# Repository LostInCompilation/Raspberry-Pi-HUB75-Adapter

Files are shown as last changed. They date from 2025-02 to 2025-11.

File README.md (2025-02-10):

# Raspberry Pi Zero HUB75 LED-Matrix Controller / Adapter

## Features
- Everything on board
- 2 parralel chains of LED-Matrix panels (each chain can habe many panels)
- Suppport for HUB75 and HUB75E (ABCD**E** address lines)
- Power for LED-Matrix panels comes from board
- I2C extension port for custom hardware (light sensor, accelrometer, ...)
- Reverse polarity protection

## 3D Board view
<p align="center" width="100%">
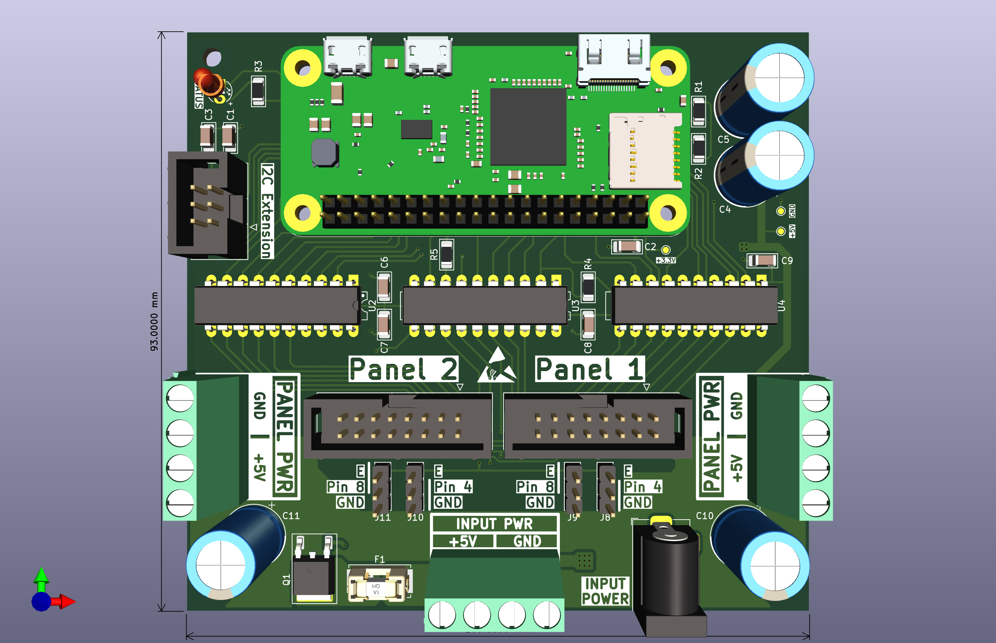
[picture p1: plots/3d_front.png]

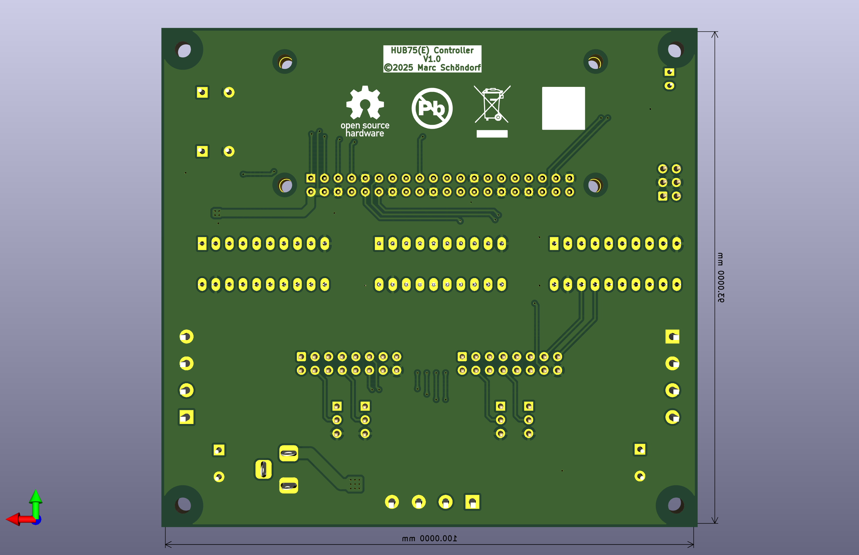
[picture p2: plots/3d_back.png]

</p>

## Board
<p align="center" width="100%">
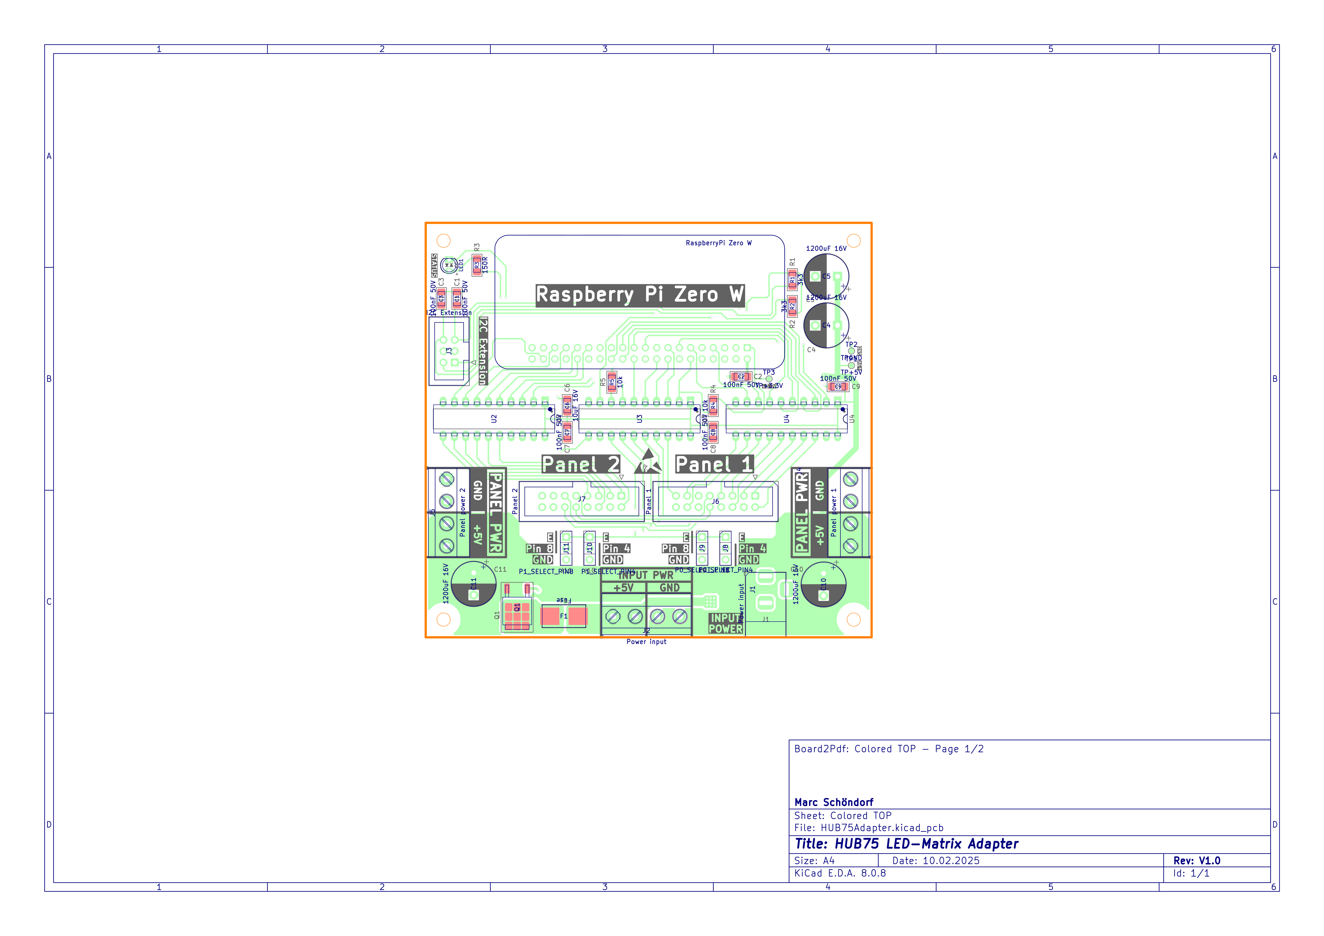
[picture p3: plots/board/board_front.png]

</p>

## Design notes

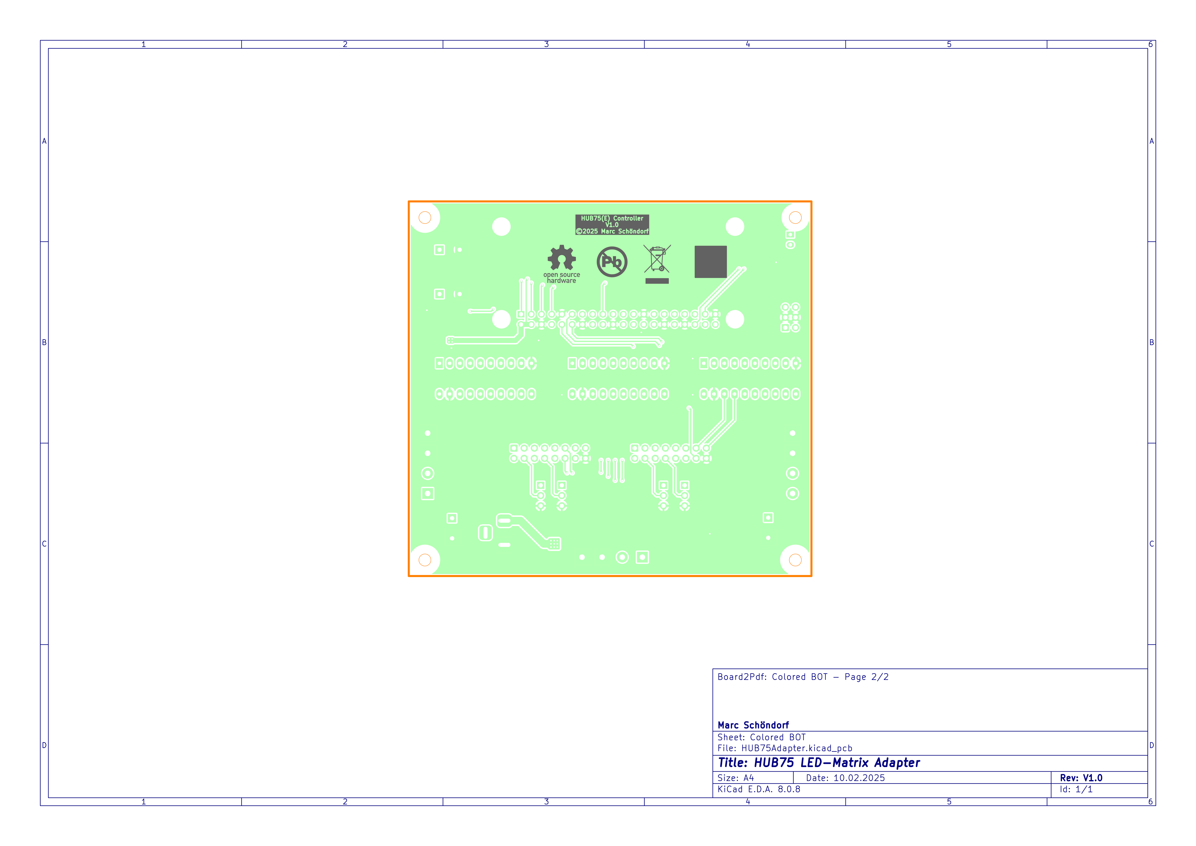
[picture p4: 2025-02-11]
plots/board/board_back.png

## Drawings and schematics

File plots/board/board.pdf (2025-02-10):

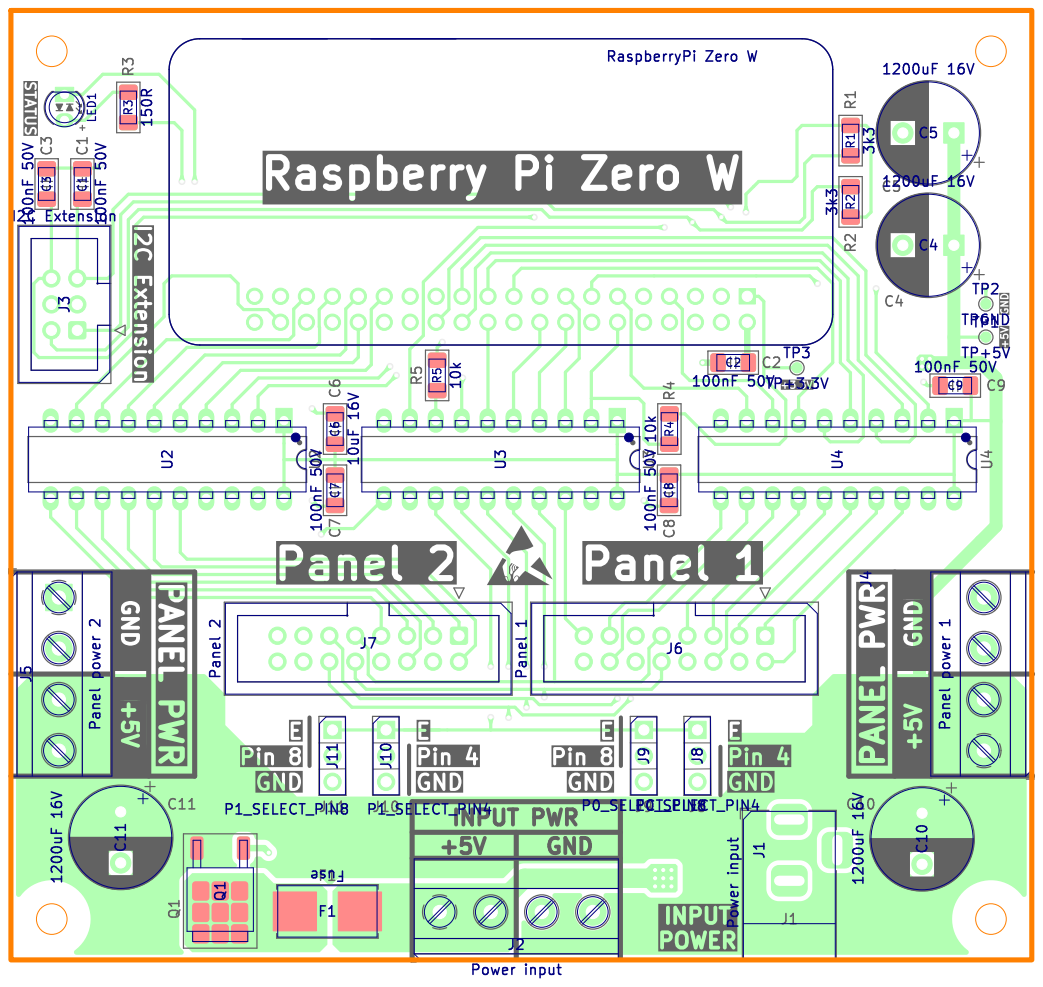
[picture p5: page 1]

INPUT | | PWR

GND

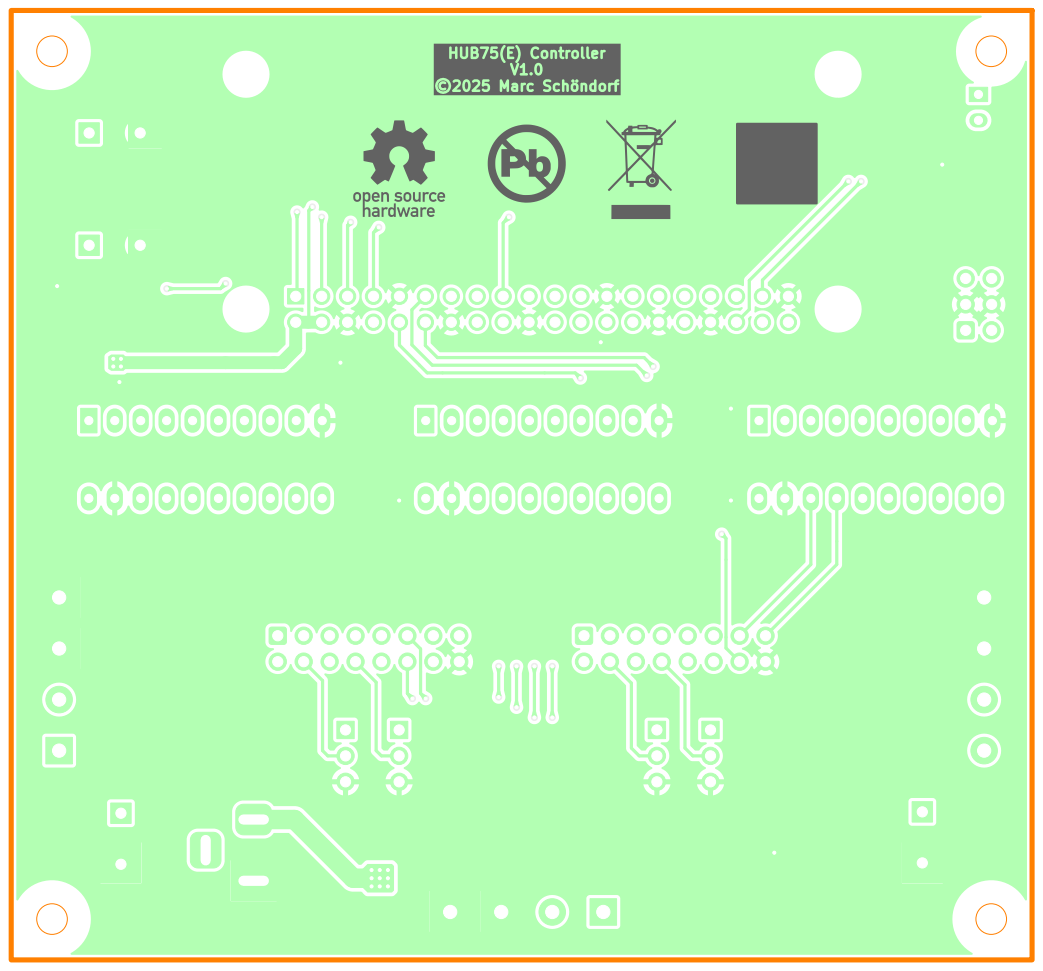
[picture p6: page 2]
D Date: 10.02.2025 KiCad; E.D.A. 8.0.8 Size: A4; Rev: V1.0; Id: 1/1 Title: HUB75 LED-Matrix; Adapter File: HUB75Adapter.kicad_pcb Sheet: Colored; BOT Marc þÿSchöndorf Board2Pdf:; Colored; BOT -; Page 2/2

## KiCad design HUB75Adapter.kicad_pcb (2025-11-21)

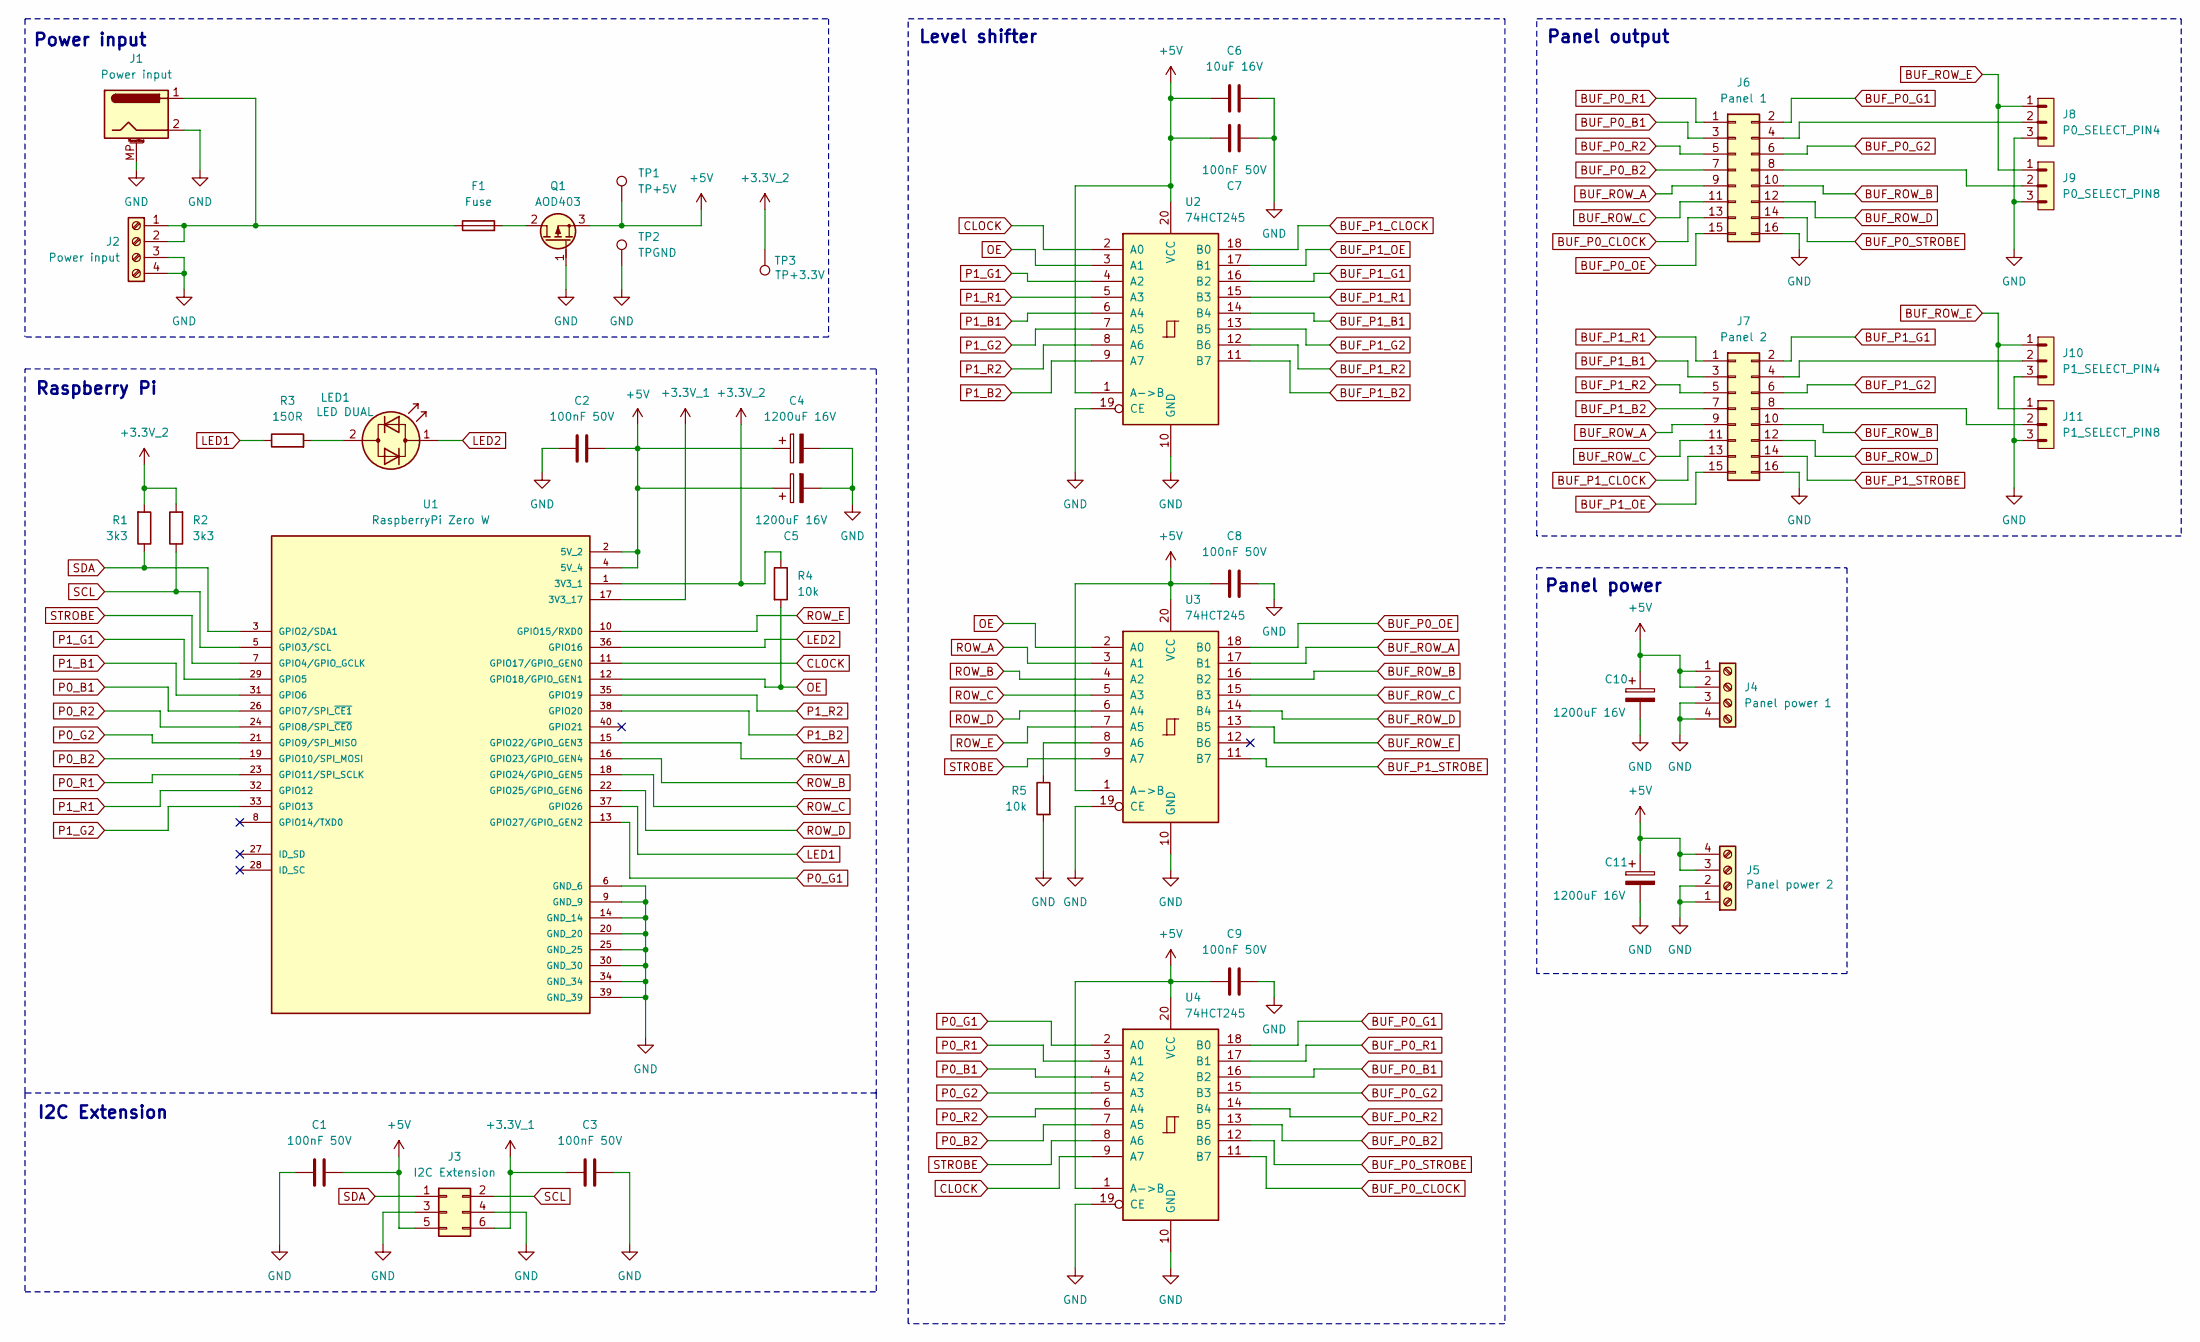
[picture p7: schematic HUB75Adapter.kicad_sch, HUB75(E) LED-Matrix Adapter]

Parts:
C1, C2, C3, C7, C8, C9: 100nF 50V; C_1206_3216Metric_Pad1.42x1.75mm_HandSolder
C4, C5, C10, C11: 1200uF 16V; CP_Radial_D10.0mm_P5.00mm
C6: 10uF 16V; C_1206_3216Metric_Pad1.42x1.75mm_HandSolder
F1: Fuse; Fuseholder_Littelfuse_Nano2_154x
J1: Power input; BarrelJack_Horizontal
J2: Power input; TerminalBlock_Phoenix_MKDS-1,5-4_1x04_P5.00mm_Horizontal
J3: I2C Extension; IDC-Header_2x03_P2.54mm_Vertical
J4: Panel power 1; TerminalBlock_Phoenix_MKDS-1,5-4_1x04_P5.00mm_Horizontal
J5: Panel power 2; TerminalBlock_Phoenix_MKDS-1,5-4_1x04_P5.00mm_Horizontal
J6: Panel 1; IDC-Header_2x08_P2.54mm_Vertical
J7: Panel 2; IDC-Header_2x08_P2.54mm_Vertical
J8: P0_SELECT_PIN4; PinHeader_1x03_P2.54mm_Vertical
J9: P0_SELECT_PIN8; PinHeader_1x03_P2.54mm_Vertical
J10: P1_SELECT_PIN4; PinHeader_1x03_P2.54mm_Vertical
J11: P1_SELECT_PIN8; PinHeader_1x03_P2.54mm_Vertical
LED1: LED DUAL; LED_D3.0mm_BiDir
Q1: AOD403; TO-252-2
R1, R2: 3k3; R_1206_3216Metric_Pad1.42x1.75mm_HandSolder
R3: 150R; R_1206_3216Metric_Pad1.42x1.75mm_HandSolder
R4, R5: 10k; R_1206_3216Metric_Pad1.42x1.75mm_HandSolder
TP1: TP+5V; TestPoint_Pad_D1.0mm
TP2: TPGND; TestPoint_Pad_D1.0mm
TP3: TP+3.3V; TestPoint_Pad_D1.0mm
U1: RaspberryPi Zero W; RaspberryPi Zero; PARTREV April 2024
U2, U3, U4: 74HCT245; DIP-20_W7.62mm_LongPads

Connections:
+3.3V_1: C3.2, J3.6, U1.17 (3V3_17)
+3.3V_2: R1.2, R2.2, R4.1, TP3.1, U1.1 (3V3_1)
+5V: C1.1, C2.2, C4.1, C5.1, C6.1, C7.1, C8.1, C9.1, C10.1, C11.1, J3.5, J4.1, J4.2, J5.3, J5.4, Q1.3 (S), TP1.1, U1.2 (5V_2), U1.4 (5V_4), U2.1 (A->B), U2.20 (VCC), U3.1 (A->B), U3.20 (VCC), U4.1 (A->B), U4.20 (VCC)
BUF_P0_B1: J6.3, U4.16 (B2)
BUF_P0_B2: J6.7, U4.13 (B5)
BUF_P0_CLOCK: J6.13, U4.11 (B7)
BUF_P0_G1: J6.2, U4.18 (B0)
BUF_P0_G2: J6.6, U4.15 (B3)
BUF_P0_OE: J6.15, U3.18 (B0)
BUF_P0_R1: J6.1, U4.17 (B1)
BUF_P0_R2: J6.5, U4.14 (B4)
BUF_P0_STROBE: J6.14, U4.12 (B6)
BUF_P1_B1: J7.3, U2.14 (B4)
BUF_P1_B2: J7.7, U2.11 (B7)
BUF_P1_CLOCK: J7.13, U2.18 (B0)
BUF_P1_G1: J7.2, U2.16 (B2)
BUF_P1_G2: J7.6, U2.13 (B5)
BUF_P1_OE: J7.15, U2.17 (B1)
BUF_P1_R1: J7.1, U2.15 (B3)
BUF_P1_R2: J7.5, U2.12 (B6)
BUF_P1_STROBE: J7.14, U3.11 (B7)
BUF_ROW_A: J6.9, J7.9, U3.17 (B1)
BUF_ROW_B: J6.10, J7.10, U3.16 (B2)
BUF_ROW_C: J6.11, J7.11, U3.15 (B3)
BUF_ROW_D: J6.12, J7.12, U3.14 (B4)
BUF_ROW_E: J8.1, J9.1, J10.1, J11.1, U3.13 (B5)
CLOCK: U1.11 (GPIO17/GPIO_GEN0), U2.2 (A0), U4.9 (A7)
GND: C1.2, C2.1, C3.1, C4.2, C5.2, C6.2, C7.2, C8.2, C9.2, C10.2, C11.2, J1.2, J1.MP (MountPin), J2.3, J2.4, J3.3, J3.4, J4.3, J4.4, J5.1, J5.2, J6.16, J7.16, J8.3, J9.3, J10.3, J11.3, Q1.1 (G), R5.2, TP2.1, U1.6 (GND_6), U1.9 (GND_9), U1.14 (GND_14), U1.20 (GND_20), U1.25 (GND_25), U1.30 (GND_30), U1.34 (GND_34), U1.39 (GND_39), U2.10 (GND), U2.19 (CE), U3.10 (GND), U3.19 (CE), U4.10 (GND), U4.19 (CE)
LED1: R3.1, U1.37 (GPIO26)
LED2: LED1.1 (KA), U1.36 (GPIO16)
unnamed: F1.1, J1.1, J2.1, J2.2
unnamed: J6.4, J8.2
unnamed: J6.8, J9.2
unnamed: J7.4, J10.2
unnamed: J7.8, J11.2
unnamed: LED1.2 (AK), R3.2
unnamed: F1.2, Q1.2 (D)
unnamed: R5.1, U3.8 (A6)
OE: R4.2, U1.12 (GPIO18/GPIO_GEN1), U2.3 (A1), U3.2 (A0)
P0_B1: U1.26 (GPIO7/SPI_~CE1), U4.4 (A2)
P0_B2: U1.19 (GPIO10/SPI_MOSI), U4.7 (A5)
P0_G1: U1.13 (GPIO27/GPIO_GEN2), U4.2 (A0)
P0_G2: U1.21 (GPIO9/SPI_MISO), U4.5 (A3)
P0_R1: U1.23 (GPIO11/SPI_SCLK), U4.3 (A1)
P0_R2: U1.24 (GPIO8/SPI_~CE0), U4.6 (A4)
P1_B1: U1.31 (GPIO6), U2.6 (A4)
P1_B2: U1.38 (GPIO20), U2.9 (A7)
P1_G1: U1.29 (GPIO5), U2.4 (A2)
P1_G2: U1.33 (GPIO13), U2.7 (A5)
P1_R1: U1.32 (GPIO12), U2.5 (A3)
P1_R2: U1.35 (GPIO19), U2.8 (A6)
ROW_A: U1.15 (GPIO22/GPIO_GEN3), U3.3 (A1)
ROW_B: U1.16 (GPIO23/GPIO_GEN4), U3.4 (A2)
ROW_C: U1.18 (GPIO24/GPIO_GEN5), U3.5 (A3)
ROW_D: U1.22 (GPIO25/GPIO_GEN6), U3.6 (A4)
ROW_E: U1.10 (GPIO15/RXD0), U3.7 (A5)
SCL: J3.2, R2.1, U1.5 (GPIO3/SCL)
SDA: J3.1, R1.1, U1.3 (GPIO2/SDA1)
STROBE: U1.7 (GPIO4/GPIO_GCLK), U3.9 (A7), U4.8 (A6)

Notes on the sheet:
Raspberry Pi
I2C Extension
Power input
Panel output
Level shifter
Panel power

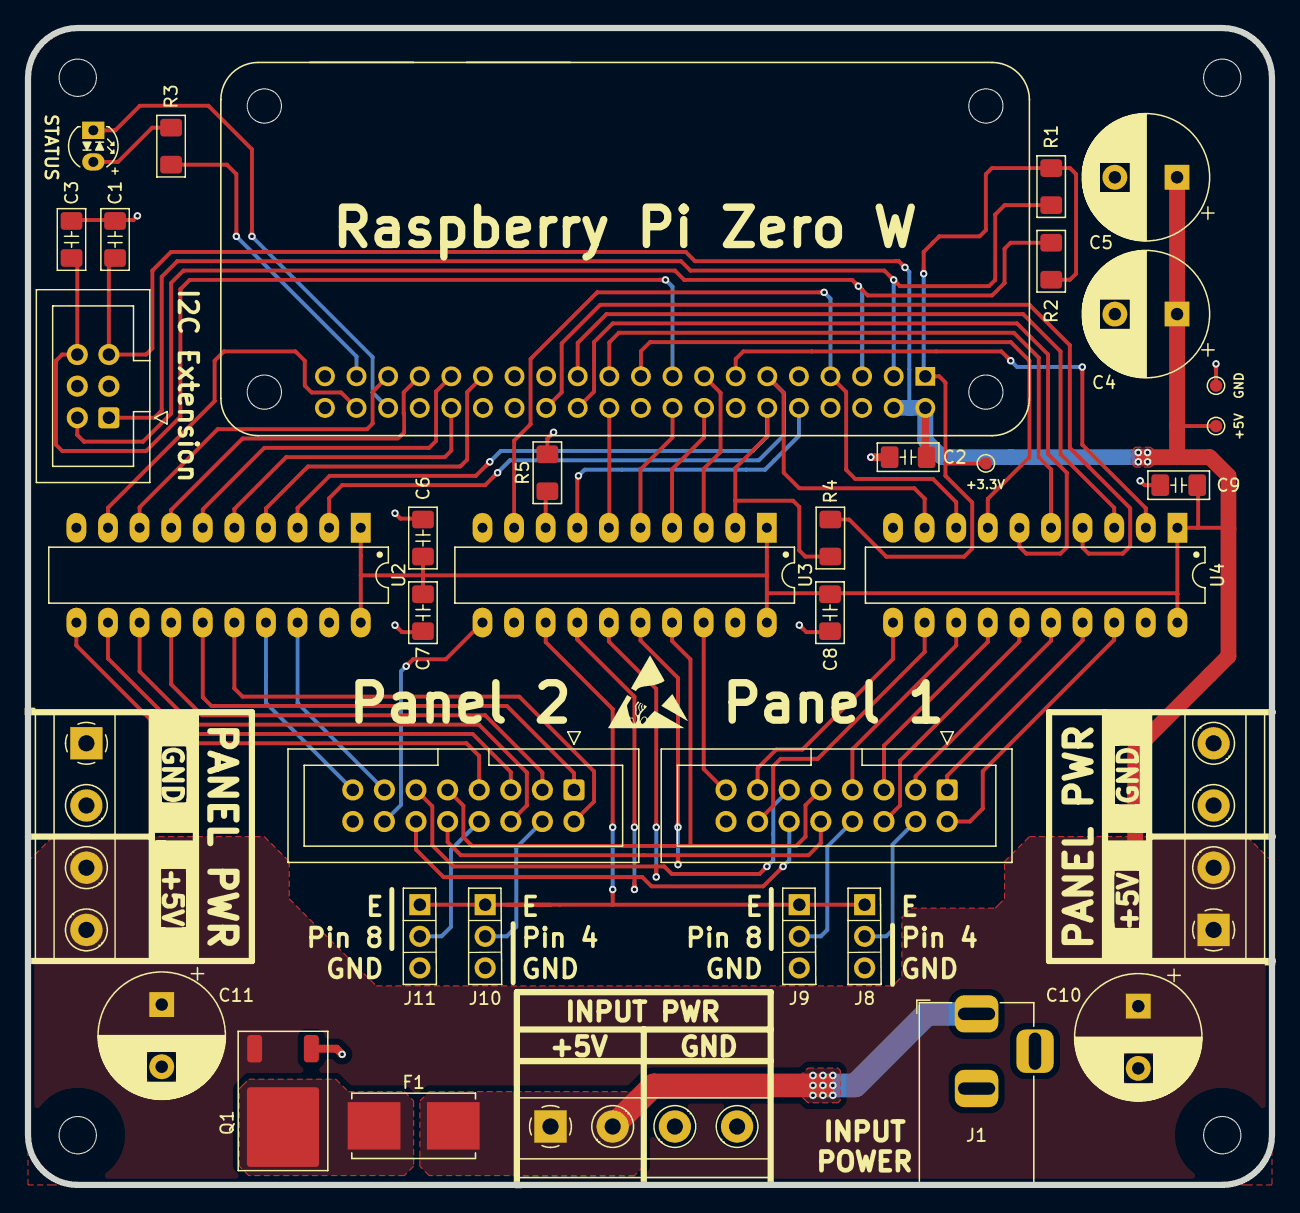
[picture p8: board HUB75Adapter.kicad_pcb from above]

Board: 2 copper layers, 100.0 x 93.0 mm, 37 parts (0 on the bottom side), 59 nets.

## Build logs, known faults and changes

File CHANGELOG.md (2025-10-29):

# Changelog

## V1.1
- Rounded PCB corners

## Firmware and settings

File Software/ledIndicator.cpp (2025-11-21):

/*
 * Bi-color LED System Activity Monitor for Raspberry Pi
 * Direct GPIO control for maximum responsiveness
 * Red = idle, Green flashes = CPU activity
 *
 * Compilation with optimizations:
 *   g++ -o led_monitor led_monitor.cpp -lpigpio -lrt -lpthread -O3 -march=native
 *
 * Run (requires sudo for direct GPIO access):
 *   sudo ./led_monitor
 *
 * Note: pigpiod daemon must NOT be running for direct GPIO access
 *   sudo systemctl stop pigpiod
 */

#include <pigpio.h>
#include <iostream>
#include <fstream>
#include <string>
#include <thread>
#include <chrono>
#include <random>
#include <csignal>
#include <cmath>
#include <sys/resource.h>

// ============================================================================
// CONFIGURATION - Adjust these settings to your preference
// ============================================================================

// GPIO pin configuration
const int PIN_A = 16;  // First LED pin
const int PIN_B = 26;  // Second LED pin

// Activity monitoring settings (optimized for responsiveness)
const int CHECK_INTERVAL_MS = 25;      // Check every 25ms (fast response)
const int MIN_FLASH_DURATION_MS = 12;  // Minimum flash duration at low CPU (milliseconds)
const int MAX_FLASH_DURATION_MS = 50;  // Maximum flash duration at high CPU (milliseconds)
const double ACTIVITY_THRESHOLD = 0.5; // Minimum CPU load to trigger flashes
const double ACTIVITY_SMOOTHING = 0.5; // Activity smoothing (lower = more responsive)

// LED brightness settings
const int GREEN_BRIGHTNESS = 32;       // Green brightness (0-255)
const int PWM_FREQUENCY = 1000;        // PWM frequency in Hz

// Flash probability settings
const double BASE_FLASH_CHANCE = 0.25; // Base probability multiplier
const double CPU_SCALING = 0.04;       // CPU influence on flash chance
const double FLASH_VARIATION = 0.3;    // Random variation in flash timing

// Minimum time between flashes
const int MIN_PAUSE_BETWEEN_FLASHES_MS = 30;

// Background mode (disable console output for lower CPU usage)
const bool BACKGROUND_MODE = false;  // Set to true when running as service

// ============================================================================

// Global flag for clean shutdown
volatile bool running = true;

// CPU stats structure
struct CPUStats {
    unsigned long long user;
    unsigned long long nice;
    unsigned long long system;
    unsigned long long idle;
    unsigned long long iowait;
    unsigned long long irq;
    unsigned long long softirq;
};

// LED control functions (RED = idle, GREEN = activity with PWM)
inline void setRed() {
    gpioPWM(PIN_B, 0);
    gpioWrite(PIN_A, 1);
    gpioWrite(PIN_B, 0);
}

inline void setGreen() {
    gpioWrite(PIN_A, 0);
    gpioPWM(PIN_B, GREEN_BRIGHTNESS);
}

inline void setOff() {
    gpioWrite(PIN_A, 0);
    gpioPWM(PIN_B, 0);
}

// Signal handler for clean shutdown
void signalHandler(int signum) {
    if (!BACKGROUND_MODE) {
        std::cout << "\n\nReceived signal " << signum << ", shutting down..." << std::endl;
    }
    running = false;
    setOff();
    gpioTerminate();
    exit(0);
}

// Read CPU stats from /proc/stat (optimized)
bool readCPUStats(CPUStats& stats) {
    std::ifstream statFile("/proc/stat");
    if (!statFile.is_open()) {
        return false;
    }

    std::string cpu;
    statFile >> cpu >> stats.user >> stats.nice >> stats.system >> stats.idle
             >> stats.iowait >> stats.irq >> stats.softirq;

    return true;
}

// CPU monitor class (optimized for minimal allocations)
class CPUMonitor {
private:
    CPUStats lastStats;
    double cpuLoad;
    bool initialized;

public:
    CPUMonitor() : cpuLoad(0.0), initialized(false) {
        readCPUStats(lastStats);
    }

    double getCPULoad() {
        CPUStats currentStats;
        if (!readCPUStats(currentStats)) {
            return cpuLoad;
        }

        if (!initialized) {
            initialized = true;
            lastStats = currentStats;
            return 0.0;
        }

        // Calculate deltas
        unsigned long long last_total = lastStats.user + lastStats.nice + lastStats.system +
                                        lastStats.idle + lastStats.iowait + lastStats.irq + lastStats.softirq;
        unsigned long long curr_total = currentStats.user + currentStats.nice + currentStats.system +
                                        currentStats.idle + currentStats.iowait + currentStats.irq + currentStats.softirq;

        unsigned long long total_diff = curr_total - last_total;
        unsigned long long idle_diff = (currentStats.idle + currentStats.iowait) -
                                       (lastStats.idle + lastStats.iowait);

        lastStats = currentStats;

        if (total_diff == 0) {
            return cpuLoad;
        }

        double currentLoad = 100.0 * (1.0 - (double)idle_diff / total_diff);
        cpuLoad = cpuLoad * ACTIVITY_SMOOTHING + currentLoad * (1.0 - ACTIVITY_SMOOTHING);

        return cpuLoad;
    }
};

int main() {
    // Set low priority for background operation
    setpriority(PRIO_PROCESS, 0, 19);

    // Initialize pigpio for direct GPIO access
    // Disable signal handling so our handlers work
    gpioCfgSetInternals(gpioCfgGetInternals() | PI_CFG_NOSIGHANDLER);

    if (gpioInitialise() < 0) {
        std::cerr << "ERROR: pigpio initialization failed!" << std::endl;
        std::cerr << "Make sure:" << std::endl;
        std::cerr << "  1. You're running with sudo" << std::endl;
        std::cerr << "  2. pigpiod daemon is NOT running (sudo killall pigpiod)" << std::endl;
        return 1;
    }

    // Setup signal handlers
    signal(SIGINT, signalHandler);
    signal(SIGTERM, signalHandler);
    signal(SIGSEGV, signalHandler);
    signal(SIGABRT, signalHandler);
    signal(SIGHUP, signalHandler);

    // Setup GPIO pins
    gpioSetMode(PIN_A, PI_OUTPUT);
    gpioSetMode(PIN_B, PI_OUTPUT);
    gpioSetPWMfrequency(PIN_B, PWM_FREQUENCY);
    gpioSetPWMrange(PIN_B, 255);

    if (!BACKGROUND_MODE) {
        std::cout << "System Activity Monitor Started (Direct GPIO)" << std::endl;
        std::cout << "LED pins: GPIO " << PIN_A << " and GPIO " << PIN_B << std::endl;
        std::cout << "Red = idle, Green flickers = CPU activity" << std::endl;
        std::cout << "Running with low priority (nice 19)" << std::endl;
        std::cout << "Press Ctrl+C to exit\n" << std::endl;
    }

    CPUMonitor monitor;
    std::random_device rd;
    std::mt19937 gen(rd());
    std::uniform_real_distribution<> dis(0.0, 1.0);

    setRed();
    bool isGreen = false;
    auto flashTimer = std::chrono::steady_clock::now();
    auto lastFlashEndTime = std::chrono::steady_clock::now();
    int currentFlashDuration = MIN_FLASH_DURATION_MS;

    while (running) {
        double cpuLoad = monitor.getCPULoad();
        auto currentTime = std::chrono::steady_clock::now();

        auto elapsed = std::chrono::duration_cast<std::chrono::milliseconds>(
            currentTime - flashTimer).count();
        auto timeSinceLastFlash = std::chrono::duration_cast<std::chrono::milliseconds>(
            currentTime - lastFlashEndTime).count();

        if (isGreen && elapsed > currentFlashDuration) {
            setRed();
            isGreen = false;
            lastFlashEndTime = currentTime;
        } else if (!isGreen && cpuLoad > ACTIVITY_THRESHOLD && timeSinceLastFlash > MIN_PAUSE_BETWEEN_FLASHES_MS) {
            double randomFactor = 0.5 + dis(gen) * FLASH_VARIATION;
            double flashProbability = BASE_FLASH_CHANCE * (cpuLoad * CPU_SCALING) * randomFactor;

            if (dis(gen) < flashProbability) {
                double cpuFactor = std::min(1.0, cpuLoad / 100.0);
                int durationRange = MAX_FLASH_DURATION_MS - MIN_FLASH_DURATION_MS;
                currentFlashDuration = MIN_FLASH_DURATION_MS + (int)(durationRange * cpuFactor);

                int randomVariation = (int)(durationRange * 0.3 * dis(gen));
                currentFlashDuration += randomVariation - (randomVariation / 2);
                currentFlashDuration = std::max(MIN_FLASH_DURATION_MS,
                                               std::min(MAX_FLASH_DURATION_MS, currentFlashDuration));

                setGreen();
                isGreen = true;
                flashTimer = currentTime;
            }
        }

        // Only show output if not in background mode
        if (!BACKGROUND_MODE) {
            int barLength = std::min(50, (int)(cpuLoad / 2));
            printf("\rCPU: %5.1f%% %s [%.*s%.*s]",
                   cpuLoad,
                   isGreen ? "*" : " ",
                   barLength, "##################################################",
                   50 - barLength, "--------------------------------------------------");
            fflush(stdout);
        }

        std::this_thread::sleep_for(std::chrono::milliseconds(CHECK_INTERVAL_MS));
    }

    setOff();
    gpioTerminate();

    if (!BACKGROUND_MODE) {
        std::cout << std::endl;
    }

    return 0;
}

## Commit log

2025-02-10 Add README. Board updates.
    [HUB75Adapter.kicad_pcb, HUB75Adapter.kicad_sch]
2025-02-10 Finish board
    [HUB75Adapter-B_Cu.gbr, HUB75Adapter-B_Mask.gbr, HUB75Adapter-B_Paste.gbr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]
2025-02-10 Added serial number to board
    [HUB75Adapter-B_Cu.gbr, HUB75Adapter-B_Mask.gbr, HUB75Adapter-B_Paste.gbr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]
2025-02-10 Added plots and BOM
    [HUB75Adapter.kicad_pcb]
2025-02-11 Added plots
    [HUB75Adapter.kicad_pcb]
2025-10-29 PCB updates
    [HUB75Adapter.kicad_pcb, HUB75Adapter.kicad_sch]
2025-11-21 Added software folder with code for controlling LED on PCB
    [HUB75Adapter.kicad_pcb]

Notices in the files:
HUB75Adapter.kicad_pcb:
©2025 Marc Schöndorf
